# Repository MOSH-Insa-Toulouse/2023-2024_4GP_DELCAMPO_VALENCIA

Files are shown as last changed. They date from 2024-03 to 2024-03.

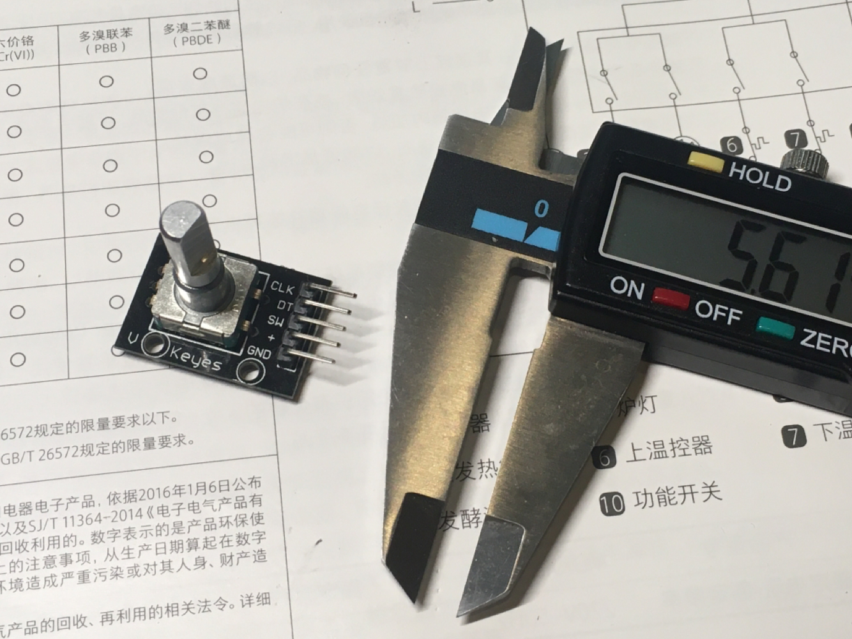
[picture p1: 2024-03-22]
KiCad/ProjetCpatKiCad_DELCAMPO_VALENCIA/ProjetCpatKiCad/Rotary Encoder - ODG/image/Measured by hand.png

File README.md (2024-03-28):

# **Projet Capteur**

## Introduction 

## Sommaire

***
  - [Livrables](#livrables)
  - [PCB Shield](#pcb-shield)
  - [Code Arduino de Mesure](#code-arduino-de-mesure)
  - [APK pour Android](#apk-pour-android)
  - [Banc de test](#banc-de-test)
  - [Code Arduino de Mesure](#code-arduino-de-mesure)
  - [Datasheet du capteur graphite](#datasheet-du-capteur-graphite)
  - [Problèmes et améliorations](#problèmes-et-améliorations)
  - [Remerciements et contact](#remerciements-et-contacts)

## Livrables

Les livrables pour ce projet sont :
 - [ ] Code Arduino permettant la mesure de R du capteur et pilotage des composants (BT, Potentiomètre, OLED)
 - [ ] PCB du Shield Arduino
 - [ ] APK Android pour le pilotage du système via smartphone
 - [ ] Datasheet du capteur de graphite
 - [ ] Banc de test pour étude du capteur sous différents types de grpahite ( 2B, HB, etc...)

## Matériel

 - 1 carte [Arduino UNO](https://store.arduino.cc/products/arduino-uno-rev3)
 - 1 écran [OLED-01](https://www.gotronic.fr/art-afficheur-oled-0-96-i2c-oled01-31506.htm)
 - 1 AOP [LTC1050](https://www.analog.com/en/products/ltc1050.html)
 - 1 Potentiomètre digital [MCP-41050](https://www.microchip.com/en-us/product/mcp41050)
 - 1 Module Bluetooth [HC-05](https://www.gotronic.fr/art-module-bluetooth-hc05-26097.htm)
 - 1 Encodeur Rotatoire [KY-040](https://www.az-delivery.de/fr/products/drehimpulsgeber-modul)
 - Résistances (X2 100kOhm, X1 1kOhm)
 - Condensateurs (X2 100nF, X1 1uF)
 - Crayons (HB, 2B,...)
 - Modèle papier pour capteur

## PCB Shield

### Symboles et empreintes des composants

### Schématique

### Placement et routage sur PCB

### Modèle 3D

### Soudage du PCB

## Code Arduino de Mesure

## APK pour Android

## Banc de test

## Datasheet

## Problèmes et améliorations

## Remerciements et contacts

**Contact:**
 - Ignacio DEL CAMPO : delcampo@insa-toulouse.fr
 - Izan VALENCIA : ivalenci@insa-toulouse.fr

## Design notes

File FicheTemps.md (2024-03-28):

# Fiche de Temps

- 10/03/2024: 1h KICAD
- 11/03/2024: 2h KICAD et ARDUINO
- 23/03/2024: 1h APK et README
- 25/03/2024: 5h APK et KICAD
- 26/03/2024: 2h APK + Arduino

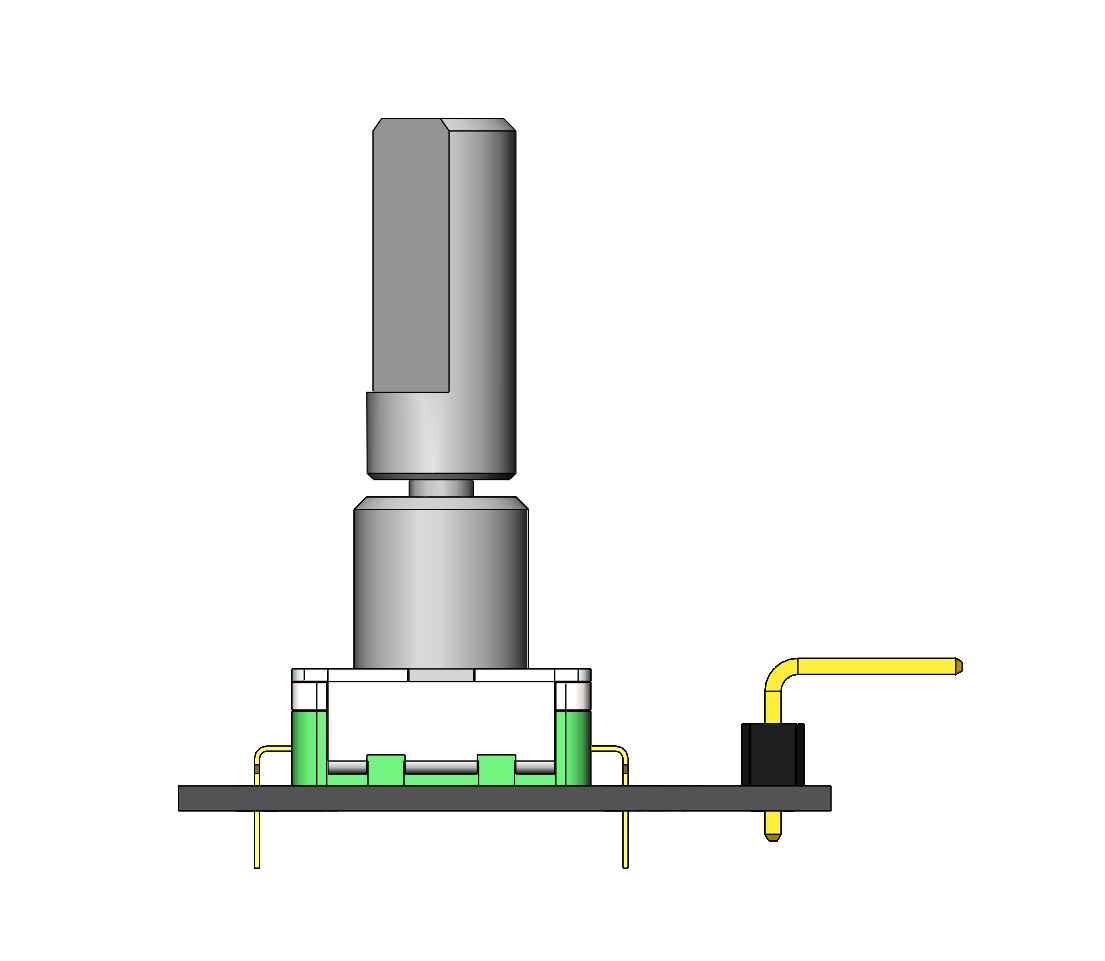
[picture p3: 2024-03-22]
KiCad/ProjetCpatKiCad_DELCAMPO_VALENCIA/ProjetCpatKiCad/Rotary Encoder - ODG/image/left.png

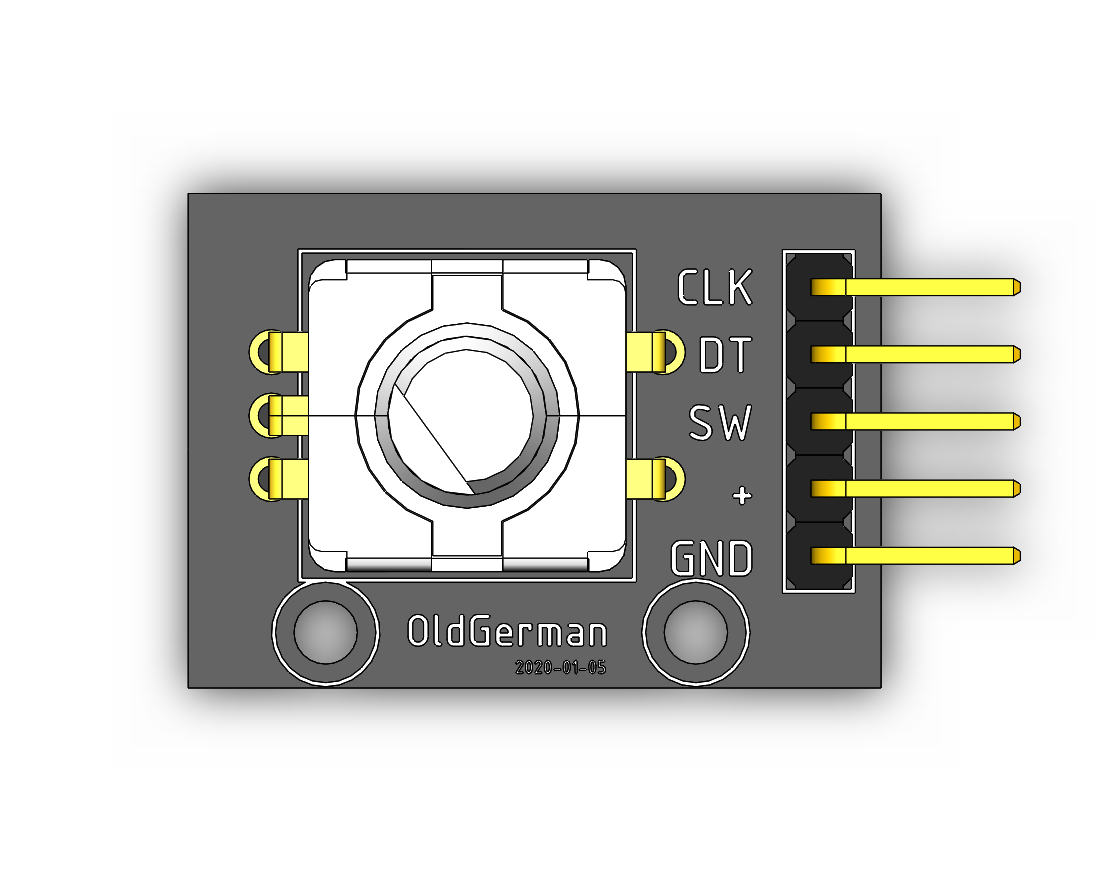
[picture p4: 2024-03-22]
KiCad/ProjetCpatKiCad_DELCAMPO_VALENCIA/ProjetCpatKiCad/Rotary Encoder - ODG/image/top.png

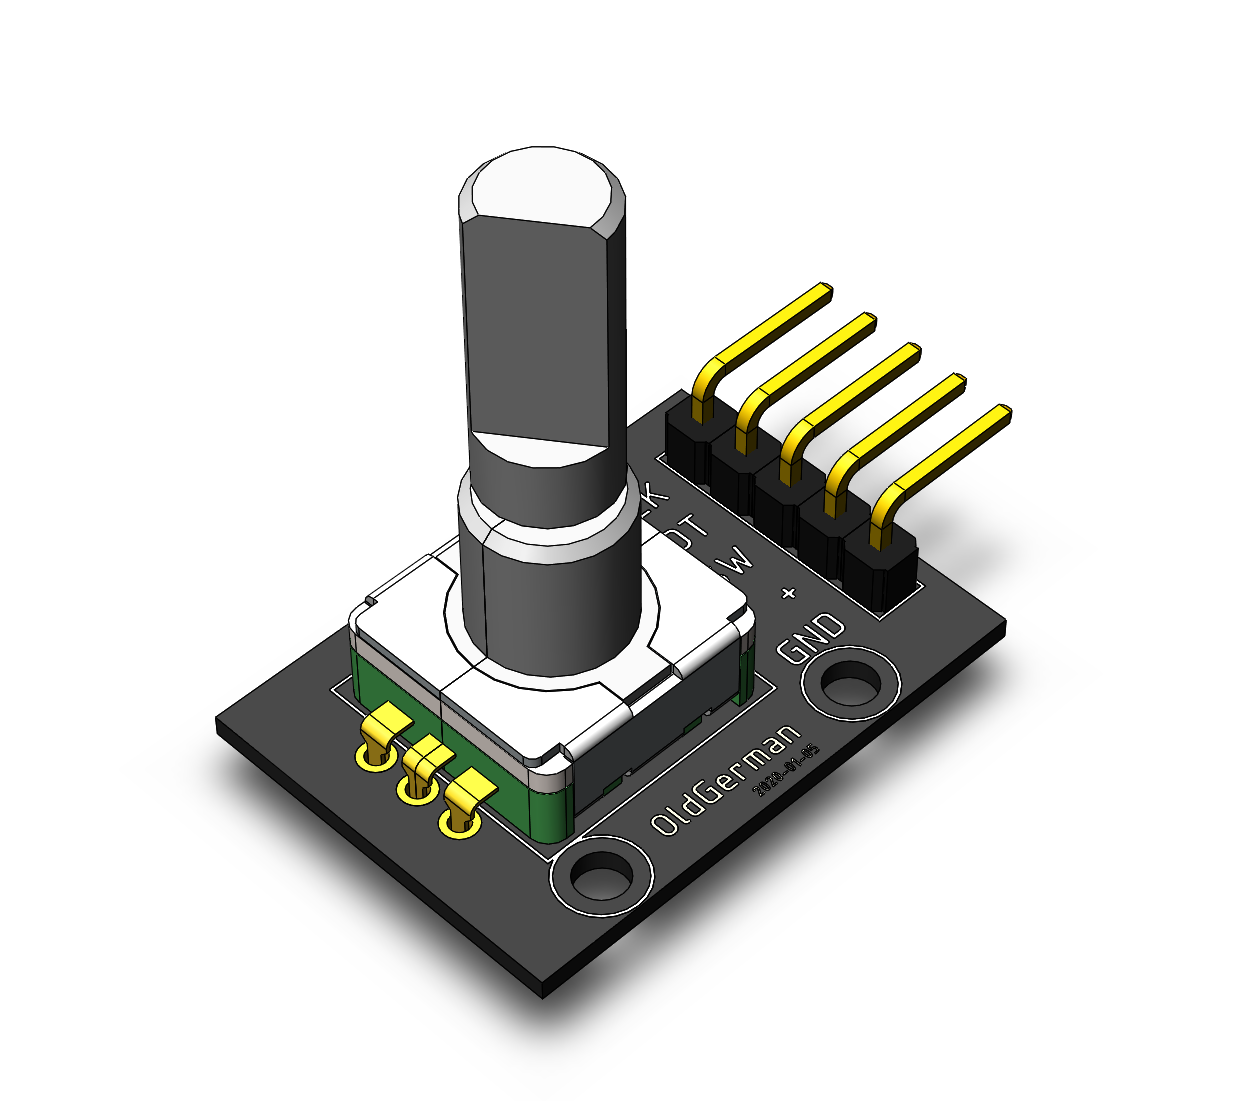
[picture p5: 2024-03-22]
KiCad/ProjetCpatKiCad_DELCAMPO_VALENCIA/ProjetCpatKiCad/Rotary Encoder - ODG/image/perspective 1 .png

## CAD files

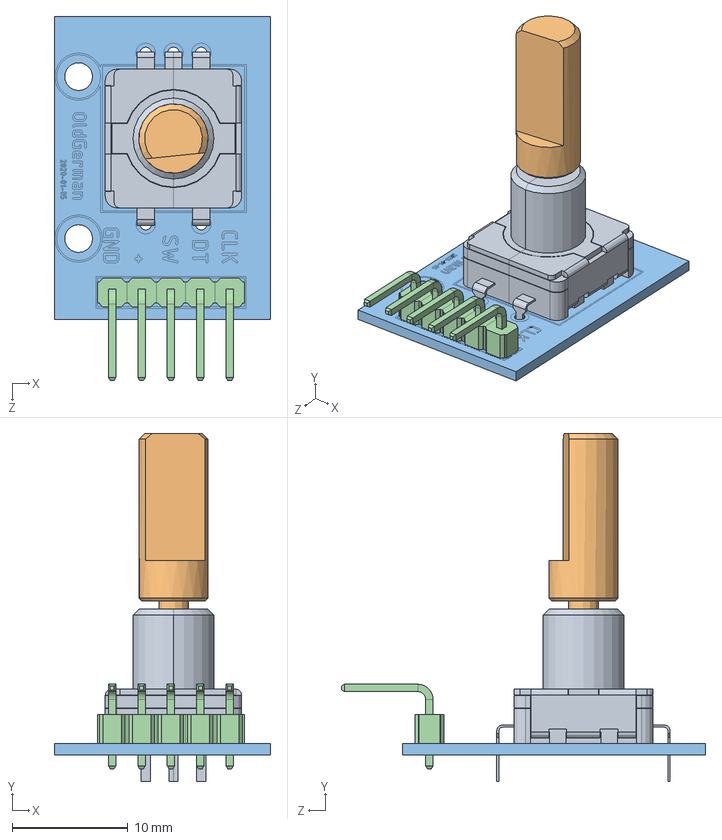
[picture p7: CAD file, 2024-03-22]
KiCad/ProjetCpatKiCad_DELCAMPO_VALENCIA/ProjetCpatKiCad/Rotary Encoder - ODG/sw2017 model/KY-040 Rotary Encoder.SLDASM
18.7 x 30.1 x 31.5 mm
Rotary Encoder
D-handle
pcb
2.54 5PIN 90

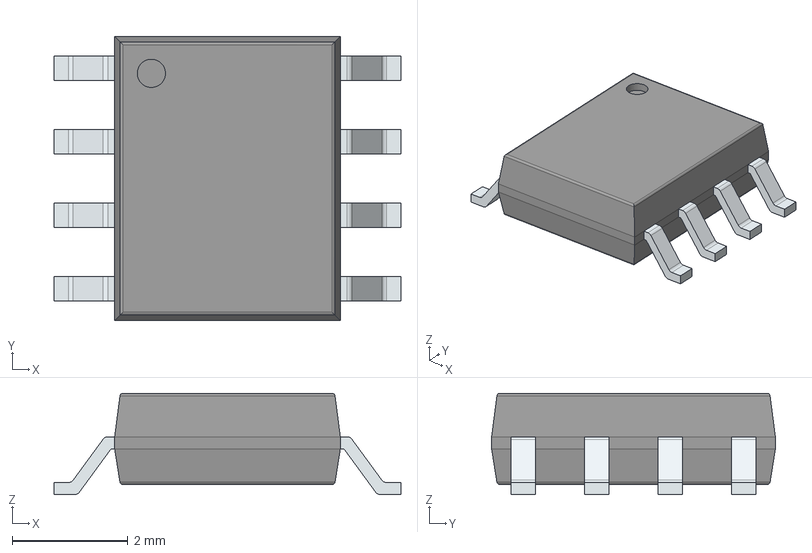
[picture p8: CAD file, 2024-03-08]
KiCad/LTC1050CS8#TRPBF/3D/LTC1050CS8#TRPBF.stp
5.99 x 4.90 x 1.75 mm
PinsArrayLR

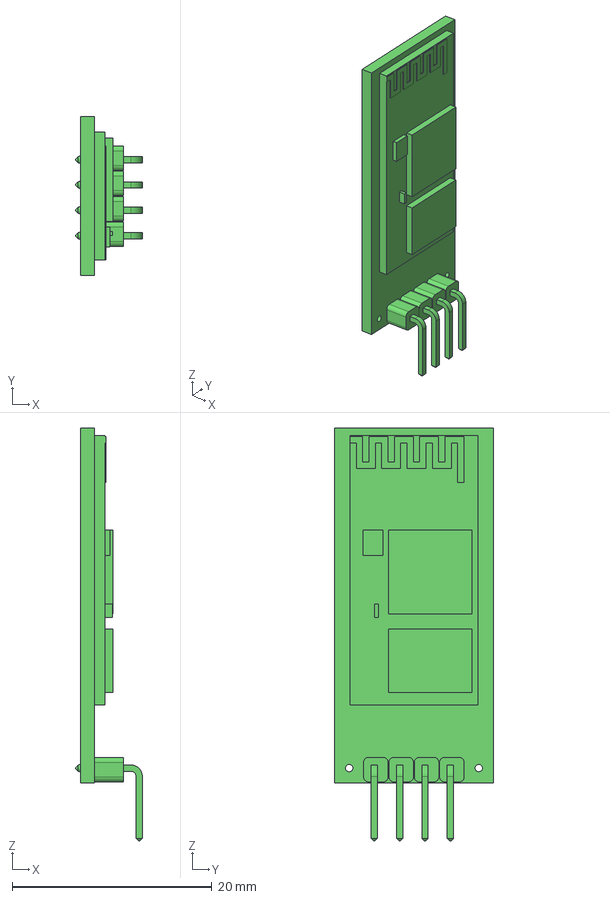
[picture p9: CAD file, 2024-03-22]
KiCad/ProjetCpatKiCad_DELCAMPO_VALENCIA/ProjetCpatKiCad/HC-05 Bluetooth Module.stp
6.68 x 16.0 x 41.4 mm

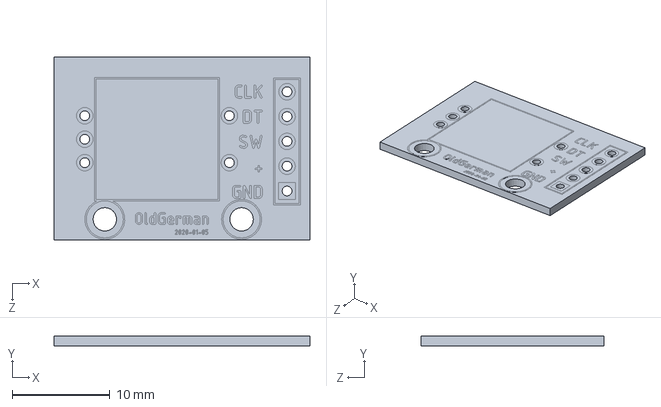
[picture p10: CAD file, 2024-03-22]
KiCad/ProjetCpatKiCad_DELCAMPO_VALENCIA/ProjetCpatKiCad/Rotary Encoder - ODG/sw2017 model/pcb.SLDPRT
26.2 x 1.02 x 18.7 mm

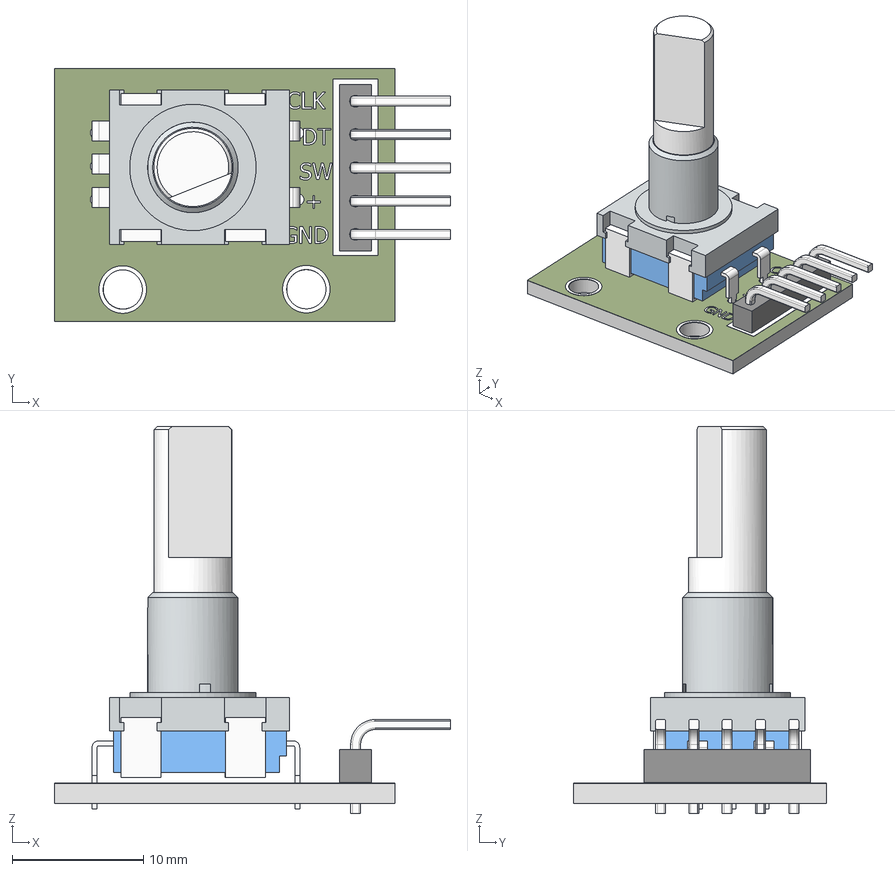
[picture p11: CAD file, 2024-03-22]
KiCad/ProjetCpatKiCad_DELCAMPO_VALENCIA/ProjetCpatKiCad/Rotary Encoder - ODG/sw2017 model/rotary+encoder_14mm_hole_spc.stp
30.2 x 19.3 x 29.6 mm
pcb
mtg flange
body_encoder
5 pin header
90d pin_header x 5
decal_encoder
pins_encoder body_2 x 5
shaft_encoder

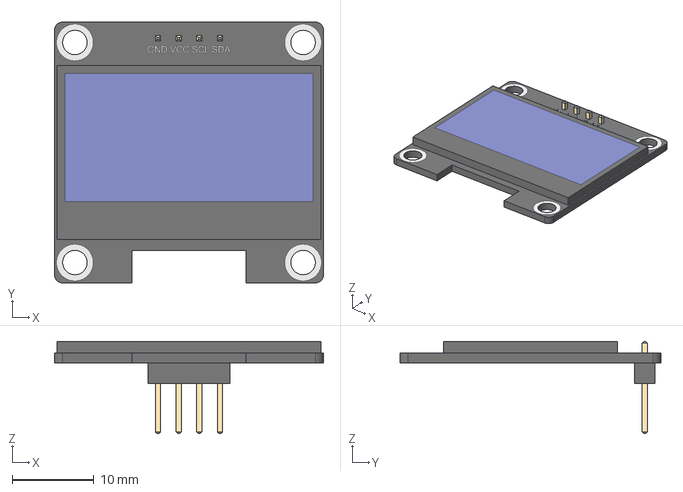
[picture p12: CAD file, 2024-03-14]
KiCad/ProjetCpatKiCad_DELCAMPO_VALENCIA/ProjetCpatKiCad/SSD1315 ZhongJingYuan v1.step
33.0 x 32.0 x 11.3 mm

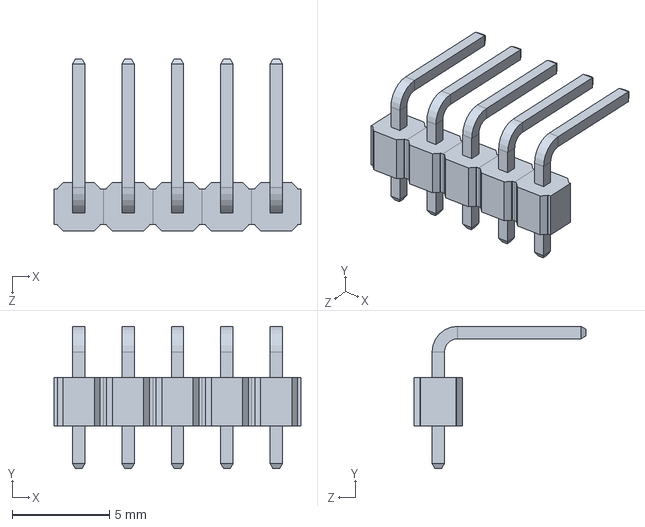
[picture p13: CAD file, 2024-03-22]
KiCad/ProjetCpatKiCad_DELCAMPO_VALENCIA/ProjetCpatKiCad/Rotary Encoder - ODG/sw2017 model/2.54 5PIN 90.SLDPRT
12.7 x 7.32 x 8.85 mm

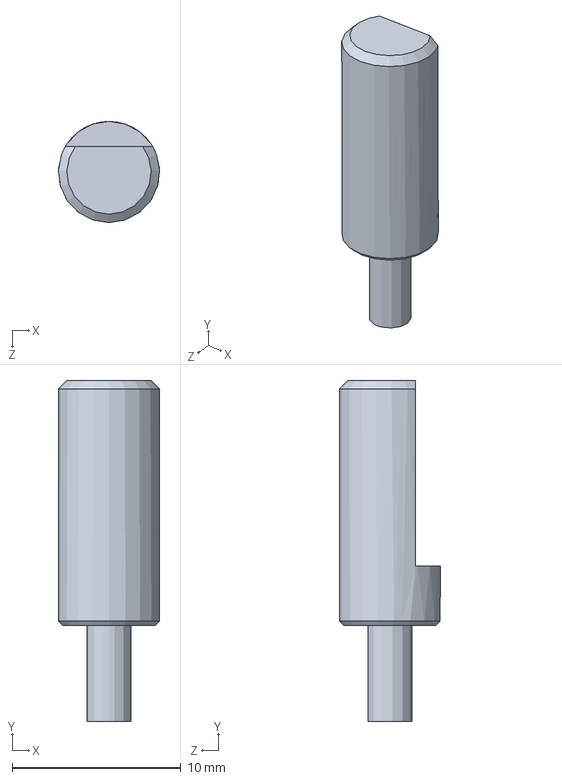
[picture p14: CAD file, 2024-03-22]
KiCad/ProjetCpatKiCad_DELCAMPO_VALENCIA/ProjetCpatKiCad/Rotary Encoder - ODG/sw2017 model/D-handle.SLDPRT
6.00 x 20.2 x 6.00 mm

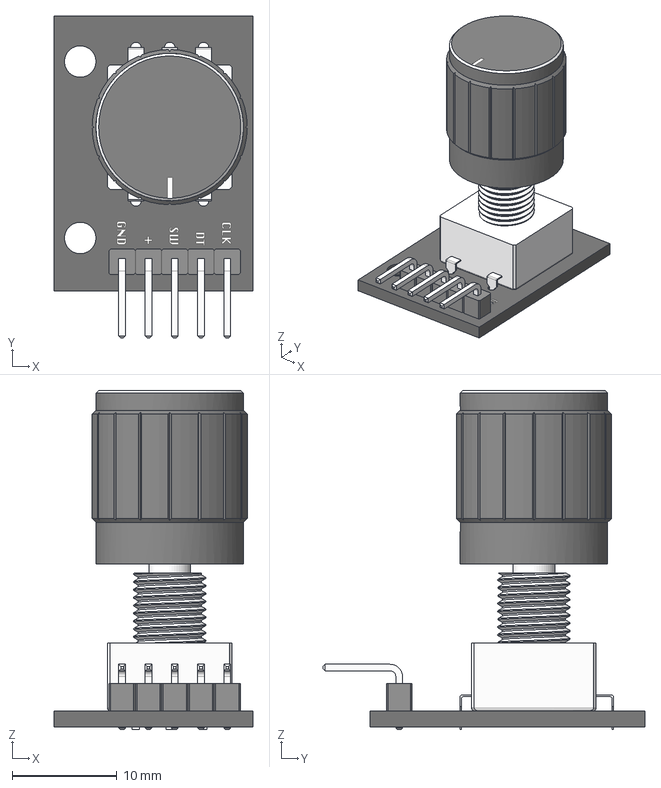
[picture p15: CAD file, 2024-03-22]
KiCad/ProjetCpatKiCad_DELCAMPO_VALENCIA/ProjetCpatKiCad/Rotary Encoder - ODG/sw2017 model/Rotary Encoder - KY-040.step
19.0 x 30.8 x 32.4 mm

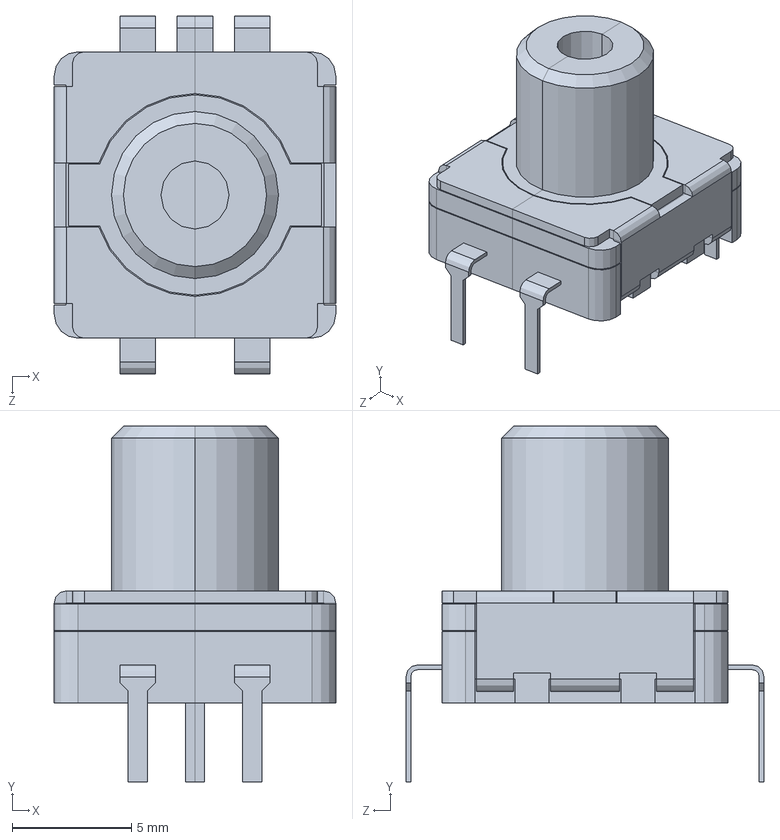
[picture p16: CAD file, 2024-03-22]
KiCad/ProjetCpatKiCad_DELCAMPO_VALENCIA/ProjetCpatKiCad/Rotary Encoder - ODG/sw2017 model/Rotary Encoder.SLDPRT
11.8 x 14.9 x 15.0 mm

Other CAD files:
KiCad/LTC1050CS8#TRPBF/Allegro/soic127p599x175-8n.psm
KiCad/LTC1050CS8#TRPBF/DEHDL/ltc1050cs8#trpbf/chips/chips.prt

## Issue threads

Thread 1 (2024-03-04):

Mise en commun du Programme Arduino

idelcampo45, 2024-03-04:
Pour mettre en place le programme Arduino général du programme, il  nous faut :

- [x] Mettre en place un menu su OLED avec plusieurs catégories: Partie MesureLocale - Partie édition Potentiomètre - Partie mode BT - etc...
- [x] Mettre en commun programme potentiomètre pour le modifier avec l'encodeur rotatoire
- [x] Vérification générale du programme

Temps aprox. de réalisation : 1h

Closed 2024-03-12.

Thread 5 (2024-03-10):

KICAD TO DO

idelcampo45, 2024-03-10:
### KICAD à faire:

- [x] footprint pour modules ( flex, encod)
- [x] Mesurer espacement pour flexsensor
- [x] Routage PCB
- [x] Label imput?
- [x] D10,11,12?

izanvr, 2024-03-11:
Espacement pour flexsensor de 2mm entre pates, mais pour suivre consignes j'ai mis 2,5mm

Closed 2024-03-14.

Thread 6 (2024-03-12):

KICAD reste à faire :

izanvr, 2024-03-12:
- Finir routage : changer R2 par le potentiomètre, chercher à eliminer les vias.
- Modèles 3D pour tous les composants hors R et C.
- À voir: changer footprint du flex sensor et de R5 pour laisser passer les câbles au milieu
-

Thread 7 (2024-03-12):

ARDUINO TO DO

idelcampo45, 2024-03-12:
### Prochaines choses à faire:

- [x] App sur MIT Inventor
- [x] Connection BT
- [x] resoudre probleme OLED qui freeze
- [x] Rajouter programme du servo pour le banc de test
- [x] Améliorations APP(notemment un graph)

Closed 2024-05-29.

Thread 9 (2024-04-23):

CORRECTION KICAD

idelcampo45, 2024-04-23:
- [x] Corriger Kicad( partie ampli, branchement pot)
- [x] Tirer nouvelle PCB

Closed 2024-05-24.

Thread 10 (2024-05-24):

Ultimos taches

idelcampo45, 2024-05-24:
- [x] Test del flex sensor e implementarlo al readme
- [x] Añadir las ameliorations al readme
- [x] Poner medidas de fuerza en los graficos
- [x] Añadir foto del banco que hemos usado

Closed 2024-05-29.

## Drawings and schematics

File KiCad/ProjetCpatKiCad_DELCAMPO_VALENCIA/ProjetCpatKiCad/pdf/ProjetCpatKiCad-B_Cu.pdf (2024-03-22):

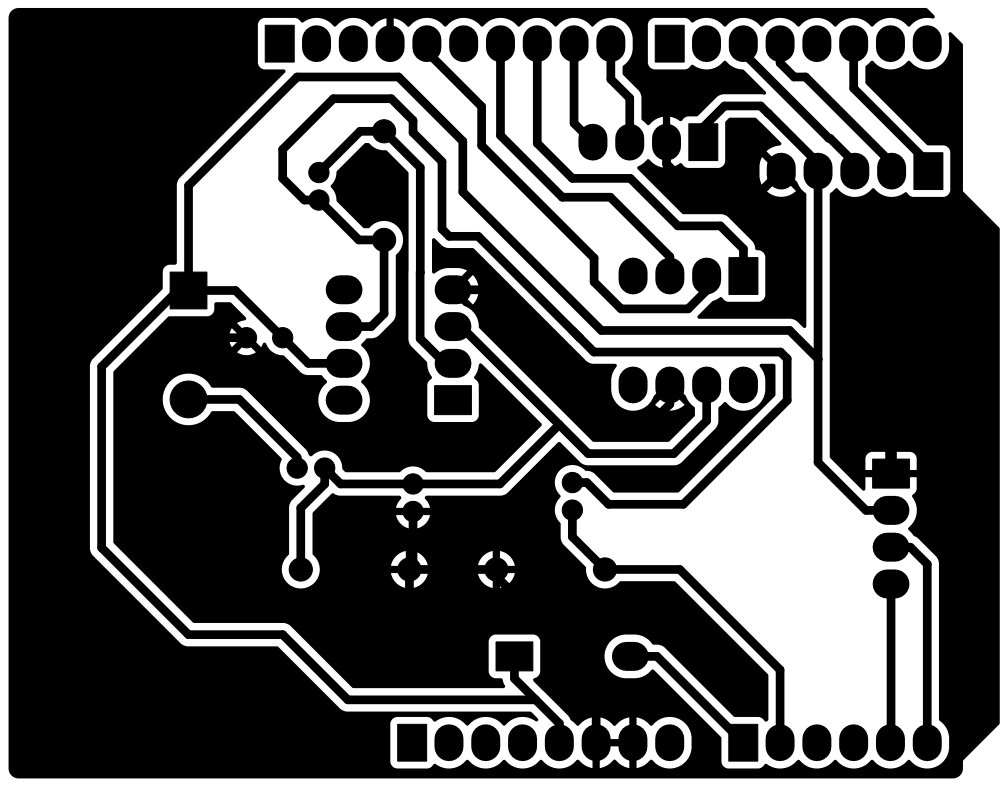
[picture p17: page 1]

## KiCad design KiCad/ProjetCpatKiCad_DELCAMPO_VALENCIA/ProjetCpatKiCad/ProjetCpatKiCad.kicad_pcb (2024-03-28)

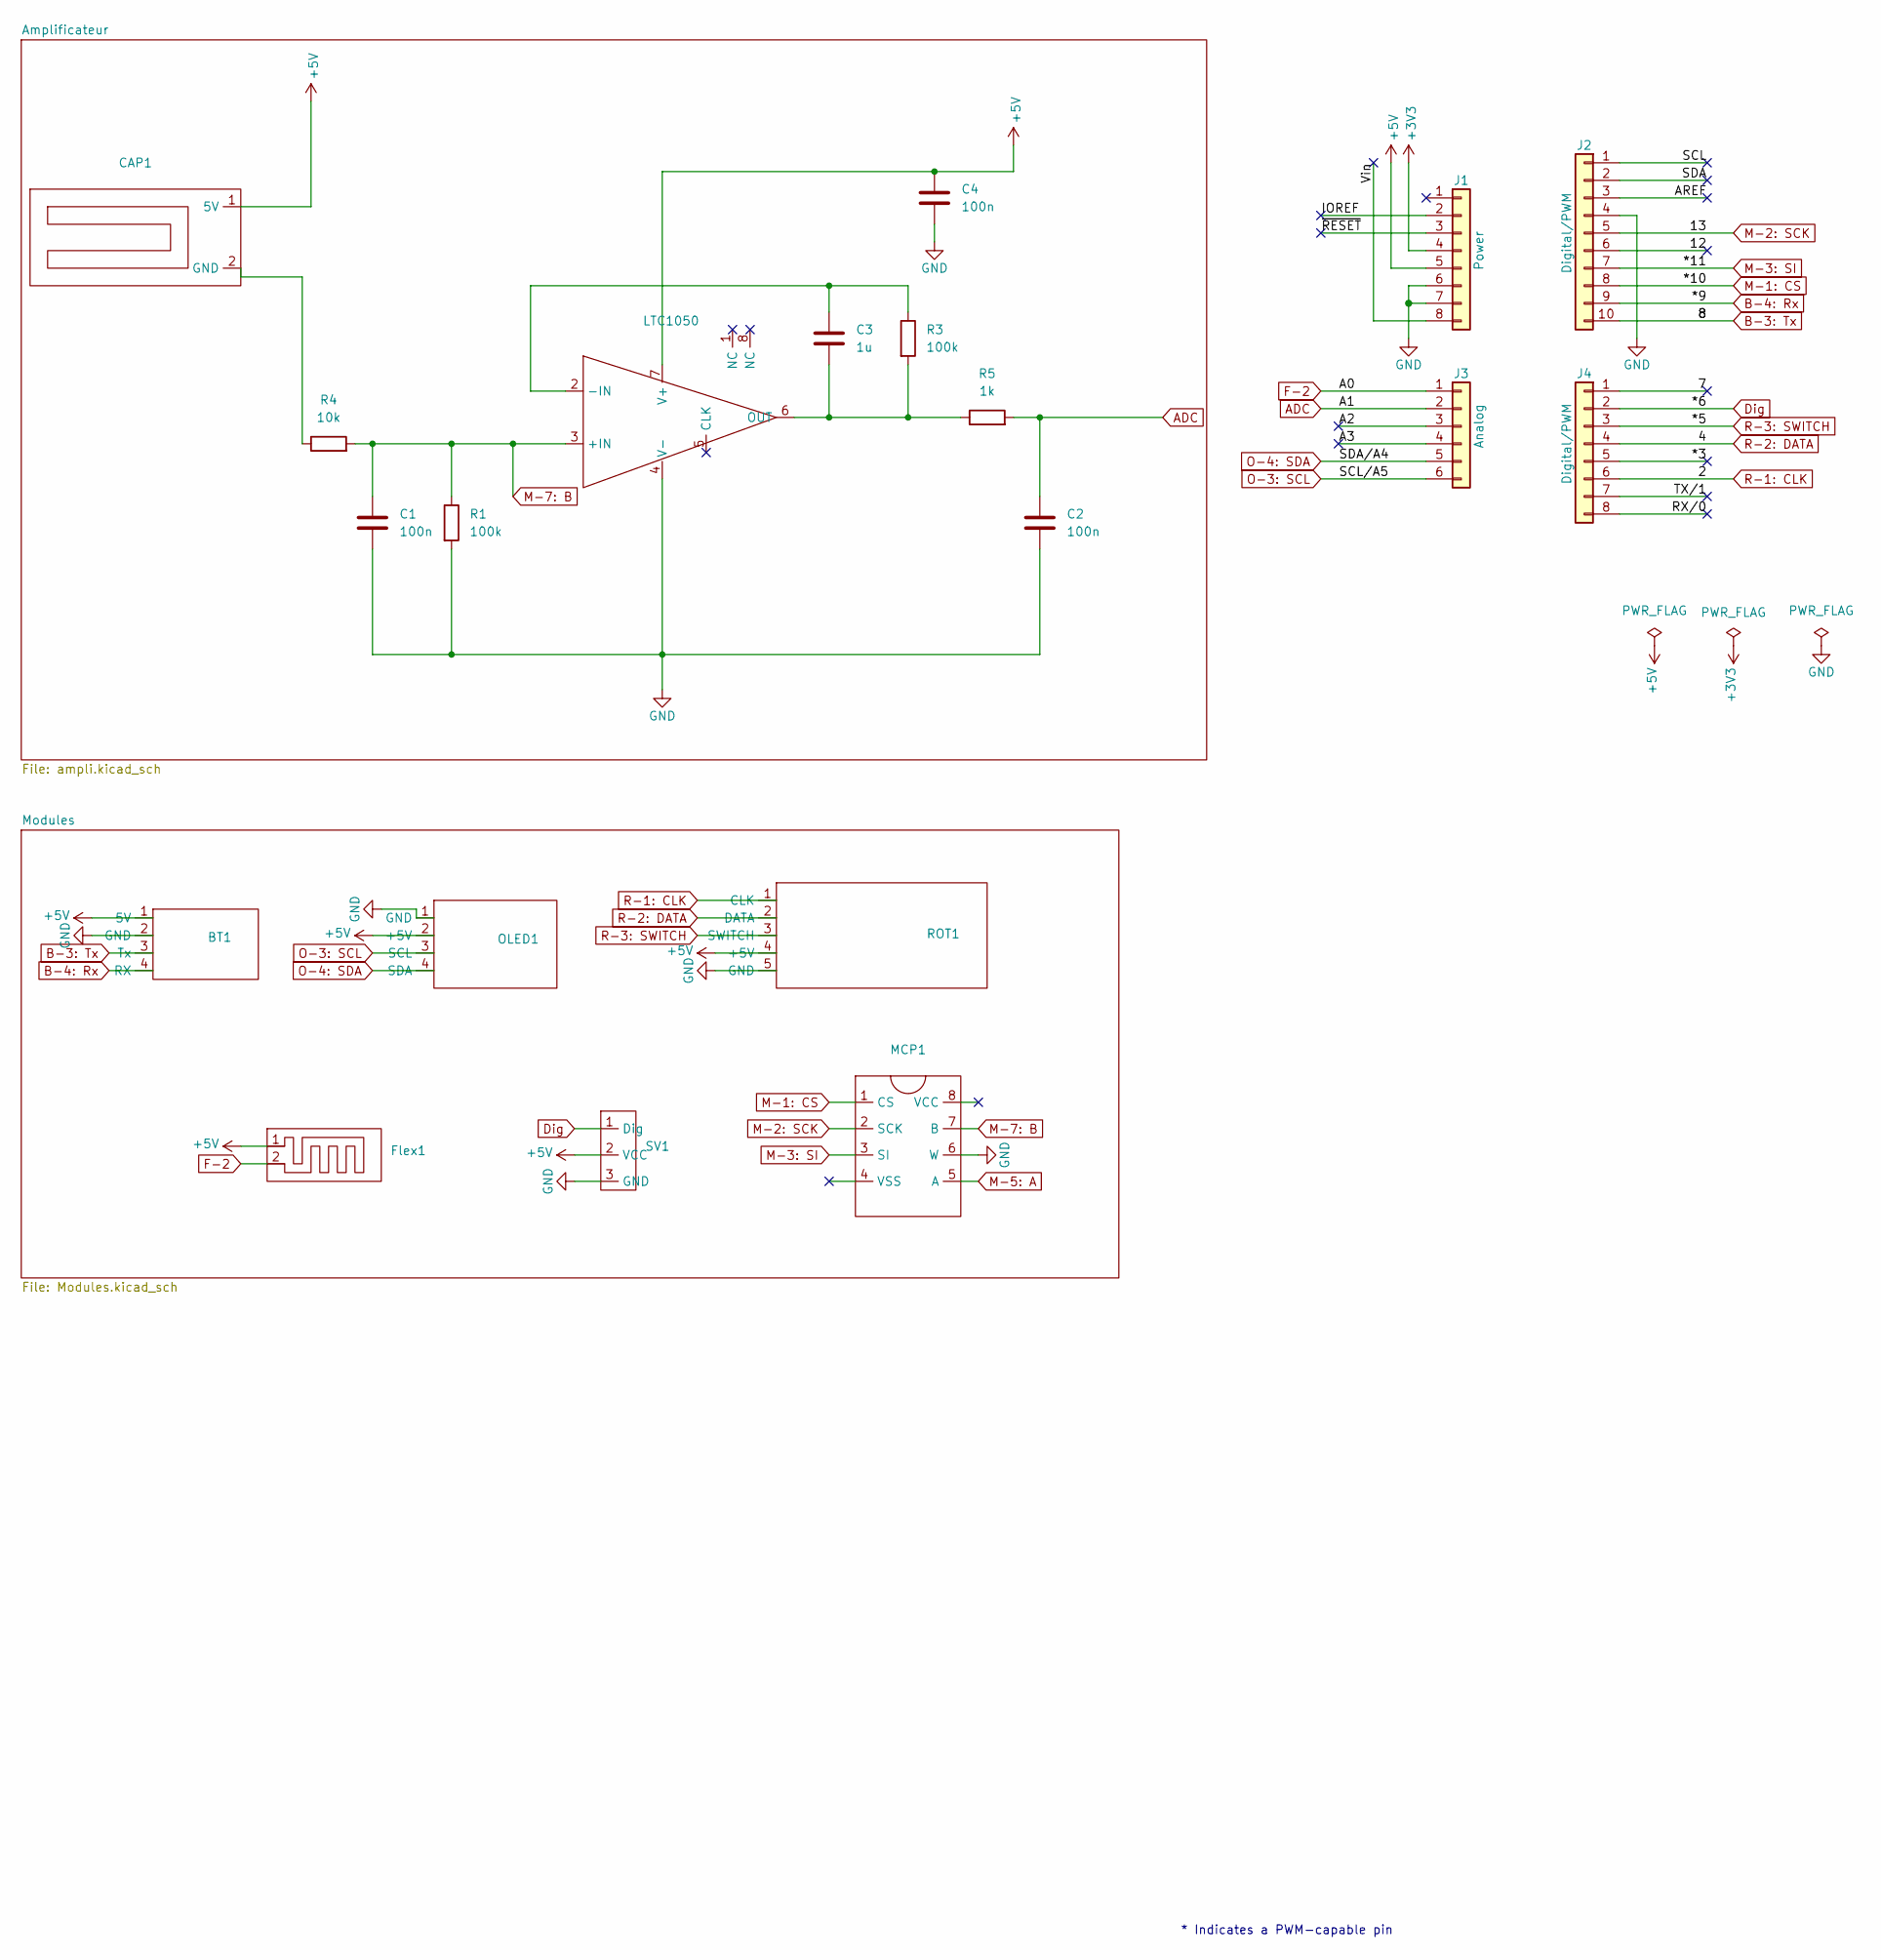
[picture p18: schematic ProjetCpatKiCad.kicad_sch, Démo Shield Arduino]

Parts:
BT1: BT-HC05
C1, C2: 100n; C_Axial_L3.8mm_D2.6mm_P7.50mm_Horizontal
C3: 1u; C_Axial_L3.8mm_D2.6mm_P7.50mm_Horizontal
C4: 100n; C_Rect_L4.6mm_W5.5mm_P2.50mm_MKS02_FKP02
CAP1: Capteur Gaz
Flex1: Flexeo
J1: Power; PinSocket_1x08_P2.54mm_Vertical
J2: Digital/PWM; PinSocket_1x10_P2.54mm_Vertical
J3: Analog; PinSocket_1x06_P2.54mm_Vertical
J4: Digital/PWM; PinSocket_1x08_P2.54mm_Vertical
LTC1050: LTC1050
MCP1: DigiPot
OLED1: OLED
R1, R3: 100k; R_Axial_DIN0204_L3.6mm_D1.6mm_P1.90mm_Vertical
R4: 10k; R_Axial_DIN0204_L3.6mm_D1.6mm_P1.90mm_Vertical
R5: 1k; R_Axial_DIN0204_L3.6mm_D1.6mm_P1.90mm_Vertical
ROT1: ROT
SV1: SIP-3

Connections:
+3V3: J1.4
+5V: BT1.1 (5V), C4.1, CAP1.1 (5V), Flex1.1, J1.5, LTC1050.7 (V+), OLED1.2 (+5V), ROT1.4 (+5V), SV1.2 (VCC)
/7: J4.1
/12: J2.6
/*3: J4.5
/A2: J3.3
/A3: J3.4
/AREF: J2.3
/IOREF: J1.2
/RX/0: J4.8
/SCL: J2.1
/SDA: J2.2
/TX/1: J4.7
/Vin: J1.8
/~RESET: J1.3
ADC: C2.1, J3.2, R5.2
B-3: Tx: BT1.3 (Tx), J2.10
B-4: Rx: BT1.4 (RX), J2.9
Dig: J4.2, SV1.1 (Dig)
F-2: Flex1.2, J3.1
GND: BT1.2 (GND), C1.2, C2.2, C4.2, J1.6, J1.7, J2.4, LTC1050.4 (V-), MCP1.6 (W), OLED1.1 (GND), R1.2, ROT1.5 (GND), SV1.3 (GND)
M-1: CS: J2.8, MCP1.1 (CS)
M-2: SCK: J2.5, MCP1.2 (SCK)
M-3: SI: J2.7, MCP1.3 (SI)
M-5: A: MCP1.5 (A)
M-7: B: C1.1, LTC1050.3 (+IN), MCP1.7 (B), R1.1, R4.2
unnamed: CAP1.2 (GND), R4.1
unnamed: C3.1, LTC1050.2 (-IN), R3.1
unnamed: C3.2, LTC1050.6 (OUT), R3.2, R5.1
O-3: SCL: J3.6, OLED1.3 (SCL)
O-4: SDA: J3.5, OLED1.4 (SDA)
R-1: CLK: J4.6, ROT1.1 (CLK)
R-2: DATA: J4.4, ROT1.2 (DATA)
R-3: SWITCH: J4.3, ROT1.3 (SWITCH)

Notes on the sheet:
* Indicates a PWM-capable pin

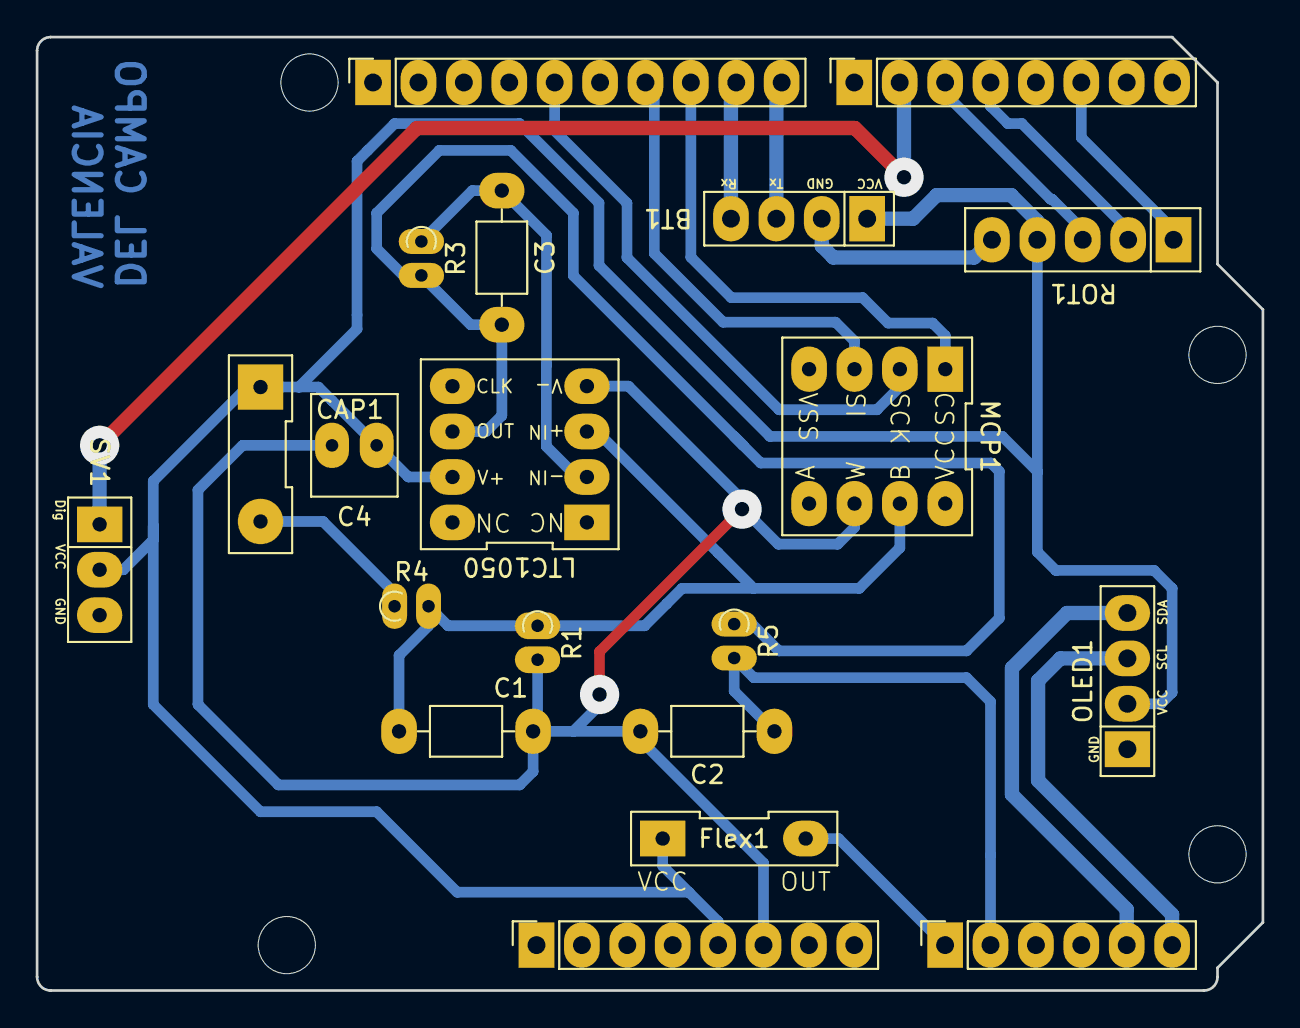
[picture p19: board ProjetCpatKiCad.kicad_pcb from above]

Board: 2 copper layers, 68.6 x 53.3 mm, 24 parts (0 on the bottom side), 19 nets.

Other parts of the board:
MH1, MH2, MH3, MH4: MountingHole_3.2mm

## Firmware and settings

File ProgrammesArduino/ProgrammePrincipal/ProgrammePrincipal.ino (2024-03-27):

/*Ça c'est le programme principal*/

/*Pour le potentiomètre variable câbler:
  ------------------------
   D10           CS  (pin 1)
   D11 (MOSI)    SI  (pin 3)
   D13 (SCK)     SCK (pin 2)
*/

#include <SPI.h>
#include <Wire.h>
#include <Servo.h>
#include <SoftwareSerial.h>
#include <Adafruit_SSD1306.h>


#define DEBUG

#define rxPinBT 9 //Broche 9 en tant que RX, à raccorder sur TX du HC-05
#define txPinBT 8 //Broche 10 en tant que TX, à raccorder sur TX du HC-05

#define ampliPin 0 //Broche A0 qui récupère Vout de l'amplificateur
#define flexSensorPin 1 //Broche A1 qui récupère Vout du flex sensor

#define baudrate 9600

#define encoder0PinCLK  2  //CLK Output A Do not use other pin for clock as we are using interrupt
#define encoder0PinDT 4  //DT Output B
#define Switch 5 // Switch connection if available

#define nombreDePixelsEnLargeur 128         // Taille de l'écran OLED, en pixel, au niveau de sa largeur
#define nombreDePixelsEnHauteur 64          // Taille de l'écran OLED, en pixel, au niveau de sa hauteur
#define brocheResetOLED         -1          // Reset de l'OLED partagé avec l'Arduino (d'où la valeur à -1, et non un numéro de pin)
#define adresseI2CecranOLED     0x3C 

Servo ServoBanc; //définition classe du servomoteur du banc
SoftwareSerial mySerial(rxPinBT ,txPinBT); //Définition du software serial
Adafruit_SSD1306 ecranOLED(nombreDePixelsEnLargeur, nombreDePixelsEnHauteur, &Wire, brocheResetOLED); //Définition classe écran OLED


volatile unsigned int encoder0Pos = 0;
int lignecursor = 1;
int n=0;
int page=0;
float R,Vflex,Rpot;

///////////////////////////////////////////////////////////////////////////////////////

//////////////////////////////////// BLUETOOTH ////////////////////////////////////////


volatile byte serialRX; // variable de reception de donnée via RX
byte serialTX; // variable de transmission de données via TX
volatile byte RX = 0; 

///////////////////////////FLEX SENSOR/////////////////////
////////////////////////////

int pos=0, pos_max =150, pos_min=20;
// Change these constants according to your project's design
const float VCC = 5;      // voltage at Ardunio 5V line
const float R_DIV = 39000.0;  // resistor used to create a voltage divider
const float flatResistance = 31000.0; // resistance when flat
const float bendResistance = 100000.0;  // resistance at 90 deg

///////////////////////////////////////////////////////////////////////////////////////

/////////////////////// MCP 42100 - Potentiomètre digital /////////////////////////////

const byte csPin           = 10;      // MCP42100 chip select pin
const int  maxPositions    = 256;     // wiper can move from 0 to 255 = 256 positions
const long rAB             = 46400;   // 100k pot resistance between terminals A and B, 
                                      // mais pour ajuster au multimètre, je mets 92500
const byte rWiper          = 150;     // 125 ohms pot wiper resistance
const byte pot0            = 0x11;    // pot0 addr // B 0001 0001
const byte pot0Shutdown    = 0x21;  


///////////////////////////////////////////////////////////////////////////////////////

/////////////////////////////////// Debouncing ////////////////////////////////////////

// the following variables are long&#039;s because the time, measured in miliseconds,
// will quickly become a bigger number than can be stored in an int.
long lastDebounceTime = 0;  // the last time the output pin was toggled
long debounceDelay = 500;    // the debounce time; increase if the output flickers


///////////////////////////////////////////////////////////////////////////////////////

//////////////////////////////////// SETUP ////////////////////////////////////////////

void setup() {
  pinMode(rxPinBT,INPUT);//setup BT
  pinMode(txPinBT,OUTPUT);  
  mySerial.begin(baudrate);
  Serial.begin(baudrate);
  
  pinMode(flexSensorPin, INPUT);//setup flexsensor
  //ServoBanc.attach(9); //setup servo

  pinMode(encoder0PinCLK, INPUT); 
  digitalWrite(encoder0PinCLK, HIGH);       // turn on pullup resistor

  pinMode(encoder0PinDT, INPUT); 
  digitalWrite(encoder0PinDT, HIGH);       // turn on pullup resistor

  pinMode(Switch, INPUT);
  digitalWrite(Switch, HIGH); 

  attachInterrupt(0, doEncoder, RISING); // encoder pin on interrupt 0 - pin2

  digitalWrite(csPin, HIGH);        // chip select default to de-selected
  pinMode(csPin, OUTPUT);           // configure chip select as output
  SPI.begin();

  // Initialisation de l'écran OLED
  if(!ecranOLED.begin(SSD1306_SWITCHCAPVCC, adresseI2CecranOLED))
    while(1);                               // Arrêt du programme (boucle infinie) si échec d'initialisation
}



///////////////////////////////////////////////////////////////////////////////////////

/////////////////////////////////////// ENCODEUR //////////////////////////////////////


void doEncoder() {
  if (!page){    //dans le menu principal
  if (digitalRead(encoder0PinDT)==HIGH) {   //SI on tourne l'encodeur vers la droite la position est incrémenté
    encoder0Pos++;
    n++;
    if (n>100){  //lorsque la position augmente de 100, le curseur du menu descend
      ecranOLED.setTextColor(SSD1306_WHITE);
     ecranOLED.setCursor(lignecursor++, 0); 
     ecranOLED.setTextColor(SSD1306_BLACK, SSD1306_WHITE);
     
     n=0;
    }
  } else {   //lorsque la position diminue de 100, le curseur du menu monte
    encoder0Pos--;
    n++;
    if (n>100){
    ecranOLED.setTextColor(SSD1306_WHITE);
    ecranOLED.setCursor(lignecursor--, 0); 
    ecranOLED.setTextColor(SSD1306_BLACK, SSD1306_WHITE);
    
    n=0;
    }
  }
  if (lignecursor>3)  // si valeur max ou min de la page est dépasée on passe à l'autre côté du menu
    lignecursor=1;
  if (lignecursor<1)
    lignecursor=3;
    
}else{                                        // dans le menu du potentiomètre
  if (digitalRead(encoder0PinDT)==HIGH) {     //si on tourne encodeur à droite, valeur du potentiomètre augmente
    encoder0Pos++;
    n++;
    if (n>50){                               // incrément de valeur du potentiomètre après 50 incréments de position de l'encodeur
      setPotWiper(pot0,pos++);
      n=0;
    }
  } else {                                   //décrément de valeur du potentiomètre après 50 décréments de position de l'encodeur
    encoder0Pos--;
    n++;
    if (n>50){
      setPotWiper(pot0,pos--);
      n=0;
    }
  }
  if (pos>255)                               // // si valeur max ou min du potentiomètre est dépasée on passe à la valeur opposée        
    pos=0;
  if (pos<0)
    pos=255;
    
}
} 
///////////////////////////////////////////////////////////////////////////////////////

//////////////////////////////// MESURE FLEX SENSOR ///////////////////////////////////

void mesureFlex() {
  // Read the ADC, and calculate voltage and resistance from it
  int ADCflex = analogRead(flexSensorPin);
  float Vflex = ADCflex * VCC / 1023.0;
  float Rflex = R_DIV * (VCC / Vflex - 1.0);
  Serial.println("Resistance: " + String(Rflex) + " ohms");

  // Use the calculated resistance to estimate the sensor's bend angle:
  float angle = map(Rflex, flatResistance, bendResistance, 0, 90.0);
  Serial.println("Bend: " + String(angle) + " degrees");
  Serial.println();
}

///////////////////////////////////////////////////////////////////////////////////////

/////////////////////// MCP 42100 - Potentiomètre digital /////////////////////////////

long setPotWiper(int addr, int pos) {
  pos = constrain(pos, 0, 255);            // limit wiper setting to range of 0 to 255
  digitalWrite(csPin, LOW);                // select chip
  SPI.transfer(addr);                      // configure target pot with wiper position
  SPI.transfer(pos);
  digitalWrite(csPin, HIGH);               // de-select chip

  // print pot resistance between wiper and B terminal
  long resistanceWB = ((rAB * pos) / maxPositions ) + rWiper;
  Serial.print("Wiper position: ");
  Serial.print(pos);
  Serial.print(" Resistance wiper to B terminal: ");
  Serial.print(resistanceWB);
  Serial.println(" ohms");
  return resistanceWB;
}

///////////////////////////////////////////////////////////////////////////////////////

///////////////////////////////// CAPTEUR GRAPHITE ////////////////////////////////////

/*
* getVoltage() – returns the voltage on the analog input defined by
* pin
*/
float getVoltage(int pin) {
  return (analogRead(pin) * 0.00488281);  //converting from a 0 to 1023 digital range
                                          // to 0 to 5 volts (each 1 reading equals ~ 5 millivolts
}



void loop()  // run over and over again
{
  
    if (!page){                  
  //affichage du menu principal
  //Serial.println(lignecursor); 
  ecranOLED.clearDisplay(); 
  ecranOLED.setTextSize(1);
  ecranOLED.setTextColor(SSD1306_WHITE);
  ecranOLED.setCursor(0, 0);  
  ecranOLED.println("Selectionnez le mode d'utilisation:");
  if (lignecursor==1 || lignecursor==0){ecranOLED.setTextColor(SSD1306_BLACK, SSD1306_WHITE);}
  ecranOLED.println("Mesure");
  ecranOLED.setTextColor(SSD1306_WHITE);
  if (lignecursor==2){ecranOLED.setTextColor(SSD1306_BLACK, SSD1306_WHITE);}
  ecranOLED.println("Calibrage Resistance"); 
  ecranOLED.setTextColor(SSD1306_WHITE);
  if (lignecursor==3){ecranOLED.setTextColor(SSD1306_BLACK, SSD1306_WHITE);}
  ecranOLED.println("Pilotage Bluetooth"); 
  ecranOLED.setTextColor(SSD1306_WHITE);             
  ecranOLED.display(); 
    if(!digitalRead (Switch) && millis()-lastDebounceTime>=debounceDelay && page==0 ){  
    lastDebounceTime=millis();
    page=1;      //appuie du bouton --> on va vers la page souhaitée
  }}
  else
    switch(lignecursor){
      case(1):                        //Menu de affichage de tension
        while(digitalRead (Switch))
        {
          Rpot= setPotWiper(pot0,pos);
          R = ((100000+Rpot)*5/getVoltage(ampliPin))-110000;//getting the voltage reading from the temperature sensor
          float VFlex = getVoltage(flexSensorPin);
          ecranOLED.clearDisplay(); 
          ecranOLED.setTextSize(2);
          ecranOLED.setCursor(0, 0);  
          ecranOLED.println(R);
          ecranOLED.println(VFlex);
          ecranOLED.display();  
        
          Serial.println(R);
          Serial.println(VFlex);                     //printing the result
          delay(100);
          
        }
        break;
      case(2):                                // Menu de modification du potentiomètre
        page=1;                     
        while(digitalRead (Switch))
        {
    
          Rpot = setPotWiper(pot0, pos);//prennant valeur du potentiomètre
          ecranOLED.clearDisplay(); 
          ecranOLED.setTextSize(2);
          ecranOLED.setCursor(0, 0);  
          ecranOLED.println(Rpot); //affichage de la valeur du potentiomètre
          ecranOLED.display();  
        
          Serial.println(Rpot);                     //printing the result
          delay(100);
          
        }
        break;
      case(3):                         //Menu de pilotage par BT sur l'app
        ecranOLED.clearDisplay(); 
        ecranOLED.setTextSize(1);
        ecranOLED.setCursor(0, 0);  
        ecranOLED.println("Connectez vous au module BT05-23");
        ecranOLED.display();
        if(mySerial.available()){
          serialRX=mySerial.read();
          Serial.println(serialRX); 
          App(serialRX);}
        
        
            //ecranOLED.println("BT Disponible");
          
            //else{ecranOLED.println("BT Non Disponible");}

            // stocker la valeur reçue dans la variable serialRX

          
    }
    if(!digitalRead (Switch) && millis()-lastDebounceTime>=debounceDelay  && page==1){ 
      lastDebounceTime=millis();
      page=0;}  
    }                                 
  



///////////////////////////////////////////////////////////////////////////////////////

//////////////////////////////////// BLUETOOTH ////////////////////////////////////////


void App(byte serialRX){
switch (serialRX) {
            case(1): // si arduino reçois le chiffre 1 alors envoi de la position du potentiomètre
              mySerial.write(pos); 
              Serial.println(pos);
              break;
            case(2): // si arduino reçois le chiffre 2 alors envoi de la tension en sortie de l'amplificateur sur 256 bits (1octet)
              mySerial.write((byte)map(analogRead(ampliPin),0,1024,0,255));
              break;
            case(3): // si arduino reçois le chiffre 3 alors incrément de la position du potentiomètre
              setPotWiper(pot0,pos++);
              mySerial.write((byte)pos);
              //Serial.println(3);
             break; 
            case(4): // si arduino reçois le chiffre 4 alors décrément de la position du potentiomètre
              setPotWiper(pot0,pos--);
              mySerial.write((byte)pos); 
              //Serial.println(4);
              break;
              }
}

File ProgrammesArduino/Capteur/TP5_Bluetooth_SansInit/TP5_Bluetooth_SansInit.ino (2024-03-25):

/*
Programme de reception Bluetooth via le logiciel MIT APP Inventor 
- connectez deux leds sur les sorties digitales 13 et 12
- connecter le module bluetooth sur les broches 0 et 1 , puis l'alim GND 5V (une fois le programme uploadé)

Attention, avant d'uploader ce programme, veillez à débrancher le module bluetooth
car celui-ci utilise les broches 0 et 1 utilisées aussi pour uploader
un programme dans arduino

MATERIEL - MODULE BLUETOOTH V2: 
Pin 1 - VCC => 3.3V Arduino 
Pin 2 - TX => RX Arduino 
Pin 3 - RX => TX Arduino 
Pin 10 - Ground => Ground Arduino

*/

/* ENTETE DECLARATIVE */
//#define DEBUG
#include <SoftwareSerial.h>
#define rxPinBT 9 //Broche 9 en tant que RX, à raccorder sur TX du HC-05
#define txPinBT 8 //Broche 10 en tant que TX, à raccorder sur TX du HC-05
SoftwareSerial mySerial(rxPinBT ,txPinBT); 

const int ledPin_Red = 12; // la led sera fixée à la broche 13
const int ledPin_Green = 13; // la led sera fixée à la broche 12
byte serialRX; // variable de reception de donnée via RX
byte serialTX; // variable de transmission de données via TX 
volatile byte RX = 0; 
boolean lastButtonState = LOW;
boolean buttonState;
int impulsion = 0; 
const int speed_serial = 9600;      // communication Bluetooth 
// digital pin 2 has a pushbutton attached to it. Give it a name:
int pushButton = 2;


// the following variables are long's because the time, measured in miliseconds,
// will quickly become a bigger number than can be stored in an int.
long lastDebounceTime = 0;  // the last time the output pin was toggled
long debounceDelay = 50;    // the debounce time; increase if the output flickers

void setup()
{
  Serial.begin(speed_serial); // initialisation de la connexion série (avec le module bluetooth)
  pinMode(rxPinBT,INPUT);//setup BT
  pinMode(txPinBT,OUTPUT);  
  mySerial.begin(speed_serial);// démarrage liason série bluetooth cf fonction en bas

  pinMode(ledPin_Red, OUTPUT); // fixe la pin "ledpin" en sortie
  pinMode(ledPin_Green, OUTPUT); // fixe la pin "ledpin" en sortie
  
  //Déclaration du bouton poussoir
  pinMode(pushButton, INPUT);
}

void loop() {

  if (RX){
        RX=0;  
        Serial.println(serialRX); 
        switch (serialRX) {
        case 1: // si arduino reçois le chiffre 1 alors
          digitalWrite(ledPin_Red, LOW); // allume sur la broche "ledpin"
          digitalWrite(ledPin_Green, HIGH); // allume sur la broche "ledpin"
          break;
        case 2: // si arduino reçois le chiffre 2 alors
          digitalWrite(ledPin_Red, HIGH); // allume sur la broche "ledpin"
          digitalWrite(ledPin_Green, LOW); // allume sur la broche "ledpin"
          break;
        case 3: // si arduino reçois le chiffre 3 alors "clignote"
          
          digitalWrite(ledPin_Red, LOW); // assure l'extinction de la LED VERTE
          digitalWrite(ledPin_Green, HIGH);
          delay(200);
          digitalWrite(ledPin_Green, LOW);
          delay(200);
        }
  }
  
  
  ///////////////////////////////////////
  // read the input pin: Mettre un pull-up
  boolean reading  = digitalRead(pushButton);
  //Serial.println(reading);
  // print out the state of the button:

  if (reading != lastButtonState){
     lastDebounceTime=millis();
  }
    if ((millis()-lastDebounceTime) > debounceDelay){
      if ((reading == HIGH)&& (reading != buttonState)) { 

          #ifdef DEBUG
                   Serial.print("reading:");Serial.print(reading);
                   Serial.print("|buttonState:");Serial.print(buttonState);
                   Serial.print("|buttonState_Last:");Serial.print(buttonState);
                   Serial.print("|impulsion:");
          #endif

            impulsion = impulsion + 1; 
            Serial.println(impulsion);
       }
       buttonState = reading;
     }//fin du millis
   
lastButtonState = reading;
  ///////////////////////////////////////

}//fin du loop

//La fonction serialEvent est appelé après chaque boucle loop si un caractère est arrivé sur le port
void serialEvent(){ // si arduino reçoit quelquechose sur l'entrée RX
  serialRX = mySerial.read(); // stocker la valeur reçue dans la variable SerialA 
  RX = 1; //met la valeur RX à 1
}

void setupBlueToothConnection() // fonction de configuration du module bluetooth
{
/*
  Serial.begin(speed_serial); //vitesse de bluetooth
                              //initialisation de la connexion série (avec le module bluetooth)

  //  Serial.print("\r\n+STBD=115200\r\n"); // fixe la vitesse du bluetooth
  Serial.print("\r\n+STBD=9600\r\n"); // fixe la vitesse du bluetooth
  Serial.print("\r\n+STWMOD=0\r\n"); //bluetooth en mode esclave
  Serial.print("\r\n+STNA=Arduino"); //nom de l'appareil
  Serial.print("\r\n+STPIN=0000\r\n");//code pin "0000"
  Serial.print("\r\n+STOAUT=1\r\n"); // Permit Paired device to connect me
  Serial.print("\r\n+STAUTO=0\r\n"); // Auto-connection should be forbidden here
  delay(2000); // This delay is required.
  Serial.print("\r\n+INQ=1\r\n"); //make the slave bluetooth inquirable 
  delay(2000); // This delay is required.
  Serial.flush();
*/
}

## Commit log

2024-03-01 MainProgram Added to folder
    [ProjetCpatKiCad.kicad_pcb, ProjetCpatKiCad.kicad_sch]
2024-03-01 Ajustes de carpetas
2024-03-01 Cambios TD1 Kicad
    [ProjetCpatKiCad.kicad_sch]
2024-03-01 TD1.1 Chages to KIDCAD
    [ProjetCpatKiCad.kicad_pcb, ProjetCpatKiCad.kicad_sch]
2024-03-08 Add files via upload
    MCP 41050
    [prjtcqpteur.kicad_pcb, prjtcqpteur.kicad_sch]
2024-03-08 KICAD modifs
    [ProjetCpatKiCad.kicad_sch]
2024-03-08 More kicad modifs
    [Modules.kicad_sch, ProjetCpatKiCad.kicad_sch, ampli.kicad_sch]
2024-03-08 biblioteca chulo mcp 41050
    [ProjetCpatKiCad.kicad_sch]
2024-03-08 KICAD final 08/03
    [EDI2CAP.CFG, LTC1050CS8#TRPBF.SchLib, LTC1050CS8#TRPBF.stp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]
2024-03-10 Cambios KICAD
    [ProjetCpatKiCad.kicad_pcb, ProjetCpatKiCad.kicad_sch]
2024-03-10 KICAD connections
    [ProjetCpatKiCad.kicad_pcb, ProjetCpatKiCad.kicad_sch]
2024-03-11 Añadidos librerias KICAD
    [ProjetCpatKiCad.kicad_sch]
2024-03-11 Footprints and schematics
    [ProjetCpatKiCad.kicad_sch]
2024-03-11 Librairie footprint ProjetCpatKiCad
2024-03-12 un poquito de pcb
    [ProjetCpatKiCad.kicad_pcb, ProjetCpatKiCad.kicad_sch]
2024-03-12 Codage Arduino
2024-03-14 Kicad routage
    [ProjetCpatKiCad.kicad_pcb, SSD1315 ZhongJingYuan v1.step]
2024-03-14 Changements Arduino
2024-03-14 VIA GND
    [ProjetCpatKiCad.kicad_pcb]
2024-03-14 Kicad modelos 3d
    [2.54 5PIN 90.SLDPRT, D-handle.SLDPRT, HC-05 Bluetooth Module.stp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]
2024-03-22 Kicad con servo
    [ProjetCpatKiCad.kicad_pcb, ProjetCpatKiCad.kicad_sch]
2024-03-25 kikadfinal
    Dale visto bueno
    [ProjetCpatKiCad.kicad_pcb]
2024-03-25 Cambios para APP
2024-03-27 Changements Arduino+ APK sur GIT
    [2.54 5PIN 90.SLDPRT, D-handle.SLDPRT, HC-05 Bluetooth Module.stp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]
2024-03-28 Changes PINS R et C
    [ProjetCpatKiCad.kicad_pcb]
